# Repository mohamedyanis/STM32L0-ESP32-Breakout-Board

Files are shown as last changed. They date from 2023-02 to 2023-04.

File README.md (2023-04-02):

# STM32L0-ESP32 Breakout Board



This is a small breakout Printed Circuit Board (PCB) that is based on the STM32 microcontroller as well as the ESP32 dev module.
The PCB is designed using the free and open source software <a href="https://github.com/KiCad">KiCad</a>. 

## More Details
The PCB is based on the STM32L0 series, specifically the STM32L031G6U6 microcontroller which is a low power based MCU. The MCU is operated with a High Speed Internal (HSI) clock signal of a 16 MHz crystal oscillator (No external quartz is needed).<br><br>
It's operating with an input voltage from 12V to 5V. The input voltage will be filtered and reduced to 3V3 in order to power the STM32 MCU as well as the ESP32 module.<br><br>
The purpose of this PCB is to control the temperature with a PID controller. It has two connectors for that, one for reading temperature value with a thermostat, a thermocouple, or a temperature IC (LM36/LM35) that gives an analog signal, and the other connector is used to control the temperature using a Solid State Relay (SSR) controlled by a PWM signal.<br><br>
The data read from the STM32 MCU is transmitted to the ESP32 dev module via 'USART' protocol in order to send the data to the cloud and the temperature could be controlled wirelessly anywhere with a smart phone or a web application.<br><br>
STM32 MCU can be flashed using SWD programmer and the ESP32 dev module could be programmed using a USB-to-TTL converter.<br><br>

## Features :dart:
* [x] Four layers PCB
* [x] Low power
* [x] Small size
* [x] Very easy to use

## Thank _You_!
Please :star: this repo to help us improve the quality.
<br><br>

## PCB Block Diagram
PCB System Block
:---------------------:
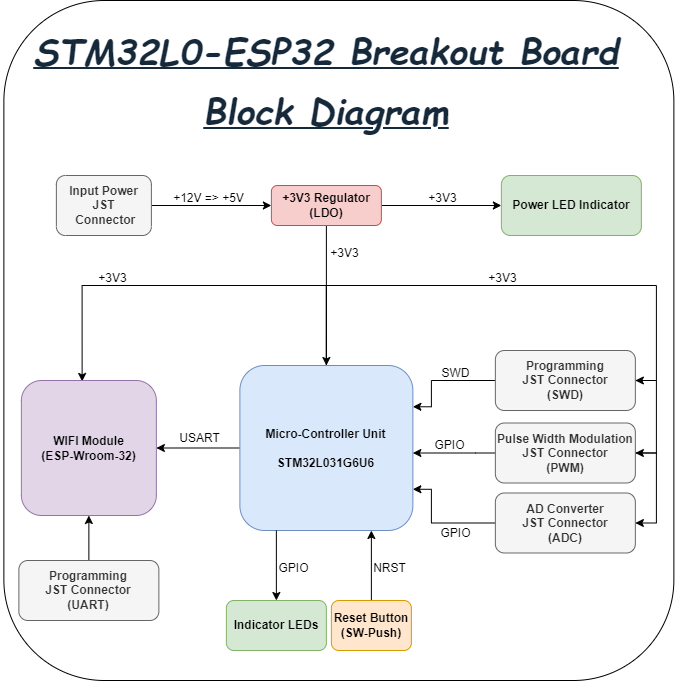
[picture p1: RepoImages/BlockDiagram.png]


## 3D Viewer
Front View           | Back View
:---------------------:|:------------------:
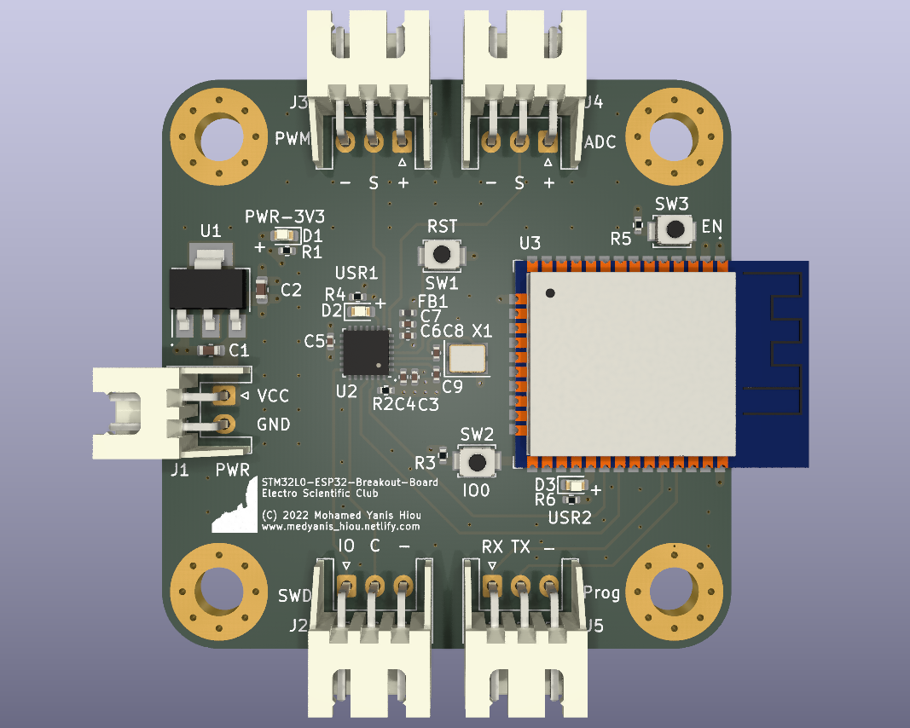
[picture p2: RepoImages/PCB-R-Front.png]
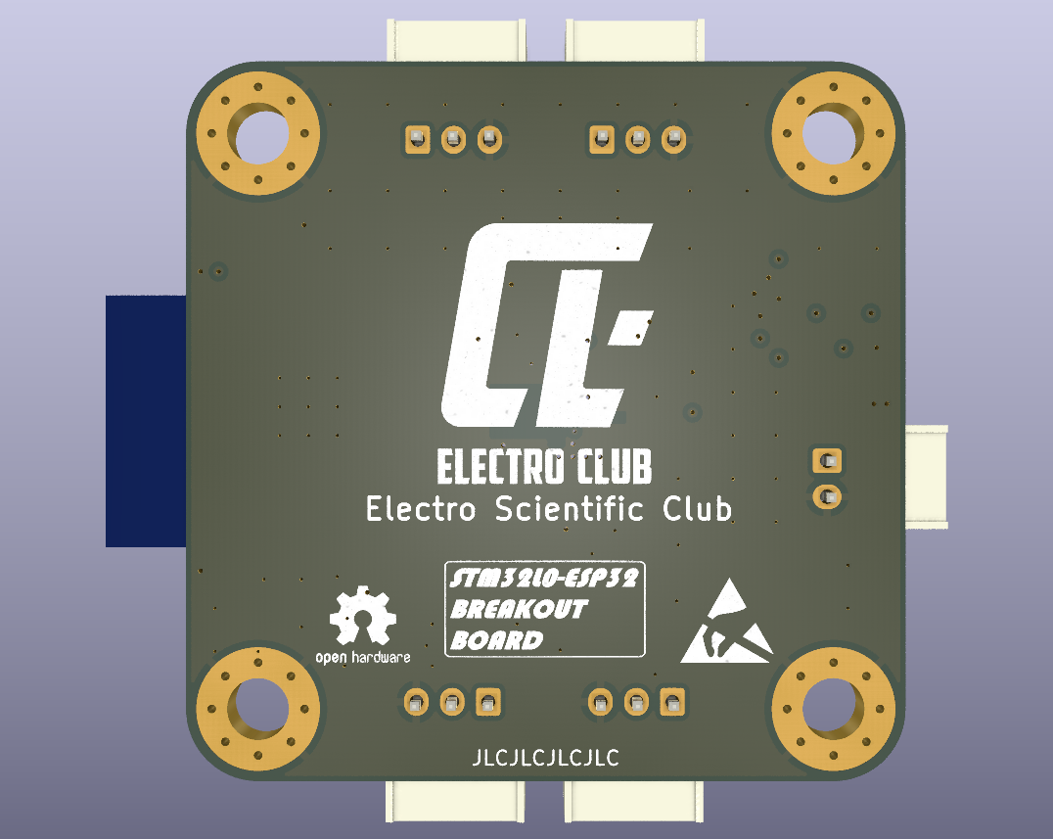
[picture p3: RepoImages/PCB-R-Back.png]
 | 
Side View 1         |  Side View 2
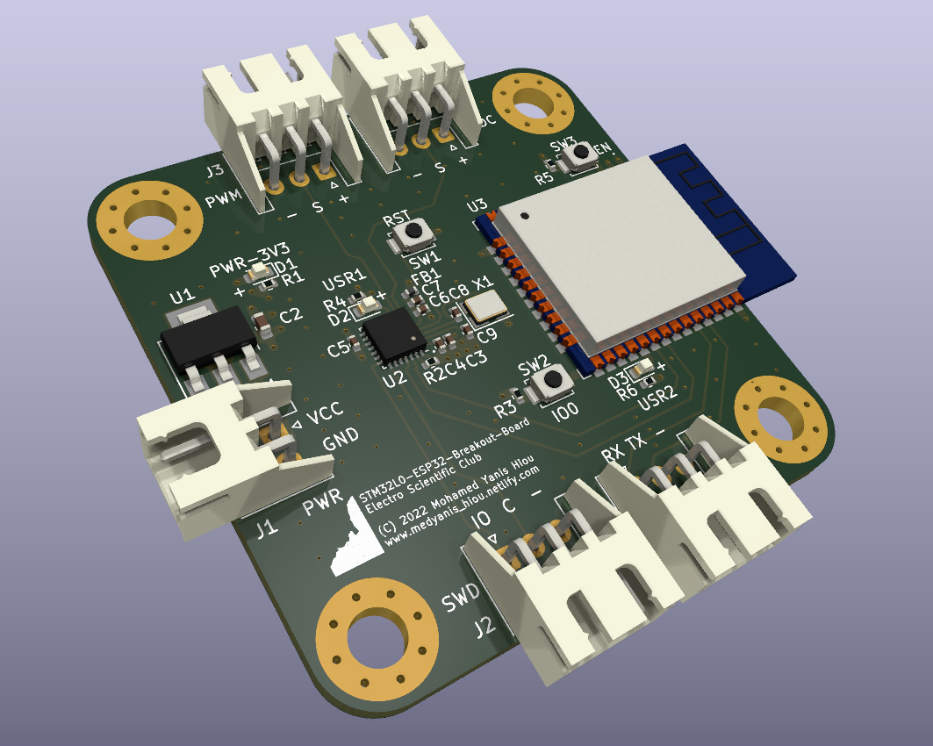
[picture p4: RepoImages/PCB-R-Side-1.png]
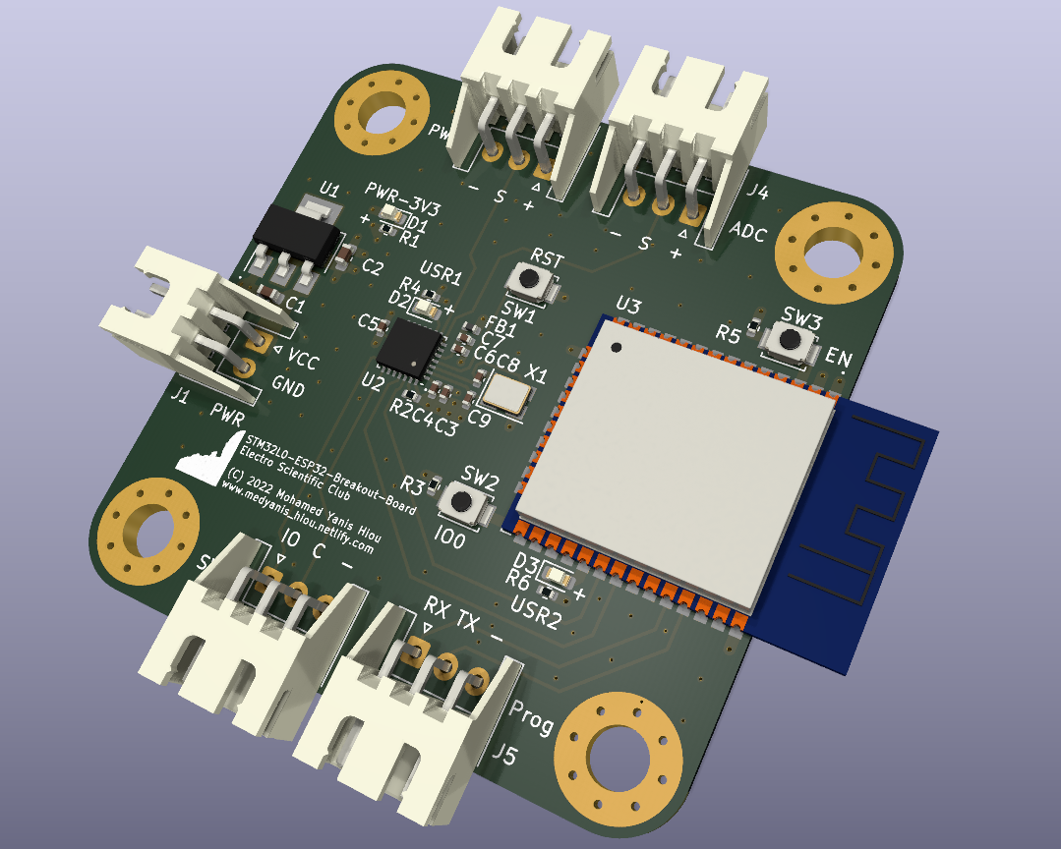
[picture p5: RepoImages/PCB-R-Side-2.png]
 | 
Side View 3         |  Side View 4
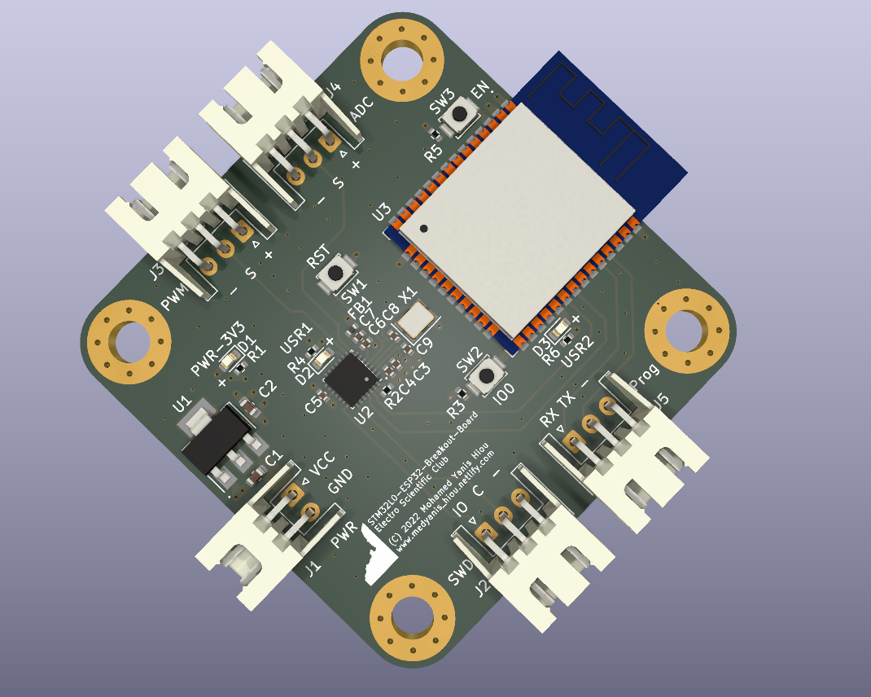
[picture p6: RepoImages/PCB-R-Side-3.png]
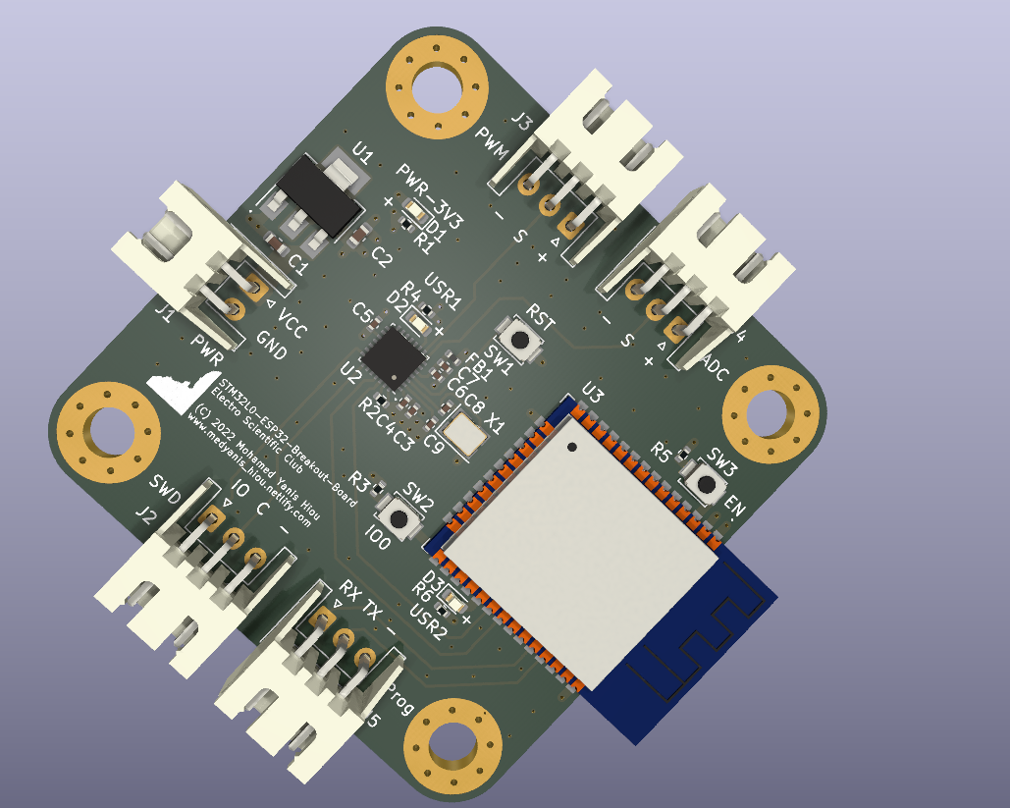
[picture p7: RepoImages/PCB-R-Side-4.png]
 | 

## Requirements

If you want to review the PCB or yoou wanna edit the schematics/layout, you only need to install KiCad software to your machine.

* Go to the <a href="https://www.kicad.org/download/">Official KiCad Download Page</a>.
* Select your operating system.
* Download the executable file and install it.

## Documentations
Open the [Datasheets](Datasheets) folder and you will find all the datasheets, applications notes, and design guidelines that help you understand the design better.

## How To Use It

1. Install this repository, click <a href="https://github.com/mohamedyanis/STM32L0-ESP32-Breakout-Board/archive/master.zip"> here </a> to install it. Or use git command:
```bach
git clone https://github.com/mohamedyanis/STM32L0-ESP32-Breakout-Board.git
```
2. Extract the folder and open it.
3. Navigate for the [Manufacturing](Manufacturing) folder.
4. Go to your best PCB manufacturer website and click on quote.
5. Upload the [STM32L0-ESP32-Breakout-Board-Gerber.rar](Manufacturing/Gerber/STM32L0-ESP32-Breakout-Board-Gerber.rar) in order to order the board.
6. In case you want to receive it assembled, upload the [STM32L0_ESP32_Breakout_Board_BOM.csv](Manufacturing/Assembly/STM32L0_ESP32_Breakout_Board_BOM.csv) and [STM32L0_ESP32_Breakout_Board_Components_Positions.csv](Manufacturing/Assembly/STM32L0_ESP32_Breakout_Board_Components_Positions.csv) files.

## License
The content of this project is licenced under the [BSD 3-Clause "New" or "Revised" License](LICENSE).

## Contributing 💡
If you want to contribute to this project and make it better with new ideas, your pull request is very welcomed.<br>
If you find any issue just put it in the repository issue section, thanks!<br><br>
.سبحَانَكَ اللَّهُمَّ وَبِحَمْدِكَ، أَشْهَدُ أَنْ لا إِلهَ إِلأَ انْتَ أَسْتَغْفِرُكَ وَأَتْوبُ إِلَيْكَ

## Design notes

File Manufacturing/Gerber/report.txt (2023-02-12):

Plotted to 'F:\Documents\Kicad\KiCad 6\STM32L0_ESP32_Breakout_Board\Manufacturing\Gerber\STM32L0_ESP32_Breakout_Board-F_Cu.gbr'.
Plotted to 'F:\Documents\Kicad\KiCad 6\STM32L0_ESP32_Breakout_Board\Manufacturing\Gerber\STM32L0_ESP32_Breakout_Board-In1_Cu.gbr'.
Plotted to 'F:\Documents\Kicad\KiCad 6\STM32L0_ESP32_Breakout_Board\Manufacturing\Gerber\STM32L0_ESP32_Breakout_Board-In2_Cu.gbr'.
Plotted to 'F:\Documents\Kicad\KiCad 6\STM32L0_ESP32_Breakout_Board\Manufacturing\Gerber\STM32L0_ESP32_Breakout_Board-B_Cu.gbr'.
Plotted to 'F:\Documents\Kicad\KiCad 6\STM32L0_ESP32_Breakout_Board\Manufacturing\Gerber\STM32L0_ESP32_Breakout_Board-F_Paste.gbr'.
Plotted to 'F:\Documents\Kicad\KiCad 6\STM32L0_ESP32_Breakout_Board\Manufacturing\Gerber\STM32L0_ESP32_Breakout_Board-B_Paste.gbr'.
Plotted to 'F:\Documents\Kicad\KiCad 6\STM32L0_ESP32_Breakout_Board\Manufacturing\Gerber\STM32L0_ESP32_Breakout_Board-F_Silkscreen.gbr'.
Plotted to 'F:\Documents\Kicad\KiCad 6\STM32L0_ESP32_Breakout_Board\Manufacturing\Gerber\STM32L0_ESP32_Breakout_Board-B_Silkscreen.gbr'.
Plotted to 'F:\Documents\Kicad\KiCad 6\STM32L0_ESP32_Breakout_Board\Manufacturing\Gerber\STM32L0_ESP32_Breakout_Board-F_Mask.gbr'.
Plotted to 'F:\Documents\Kicad\KiCad 6\STM32L0_ESP32_Breakout_Board\Manufacturing\Gerber\STM32L0_ESP32_Breakout_Board-B_Mask.gbr'.
Plotted to 'F:\Documents\Kicad\KiCad 6\STM32L0_ESP32_Breakout_Board\Manufacturing\Gerber\STM32L0_ESP32_Breakout_Board-Edge_Cuts.gbr'.
Created Gerber job file 'F:\Documents\Kicad\KiCad 6\STM32L0_ESP32_Breakout_Board\Manufacturing\Gerber\STM32L0_ESP32_Breakout_Board-job.gbrjob'.
Info: Done.

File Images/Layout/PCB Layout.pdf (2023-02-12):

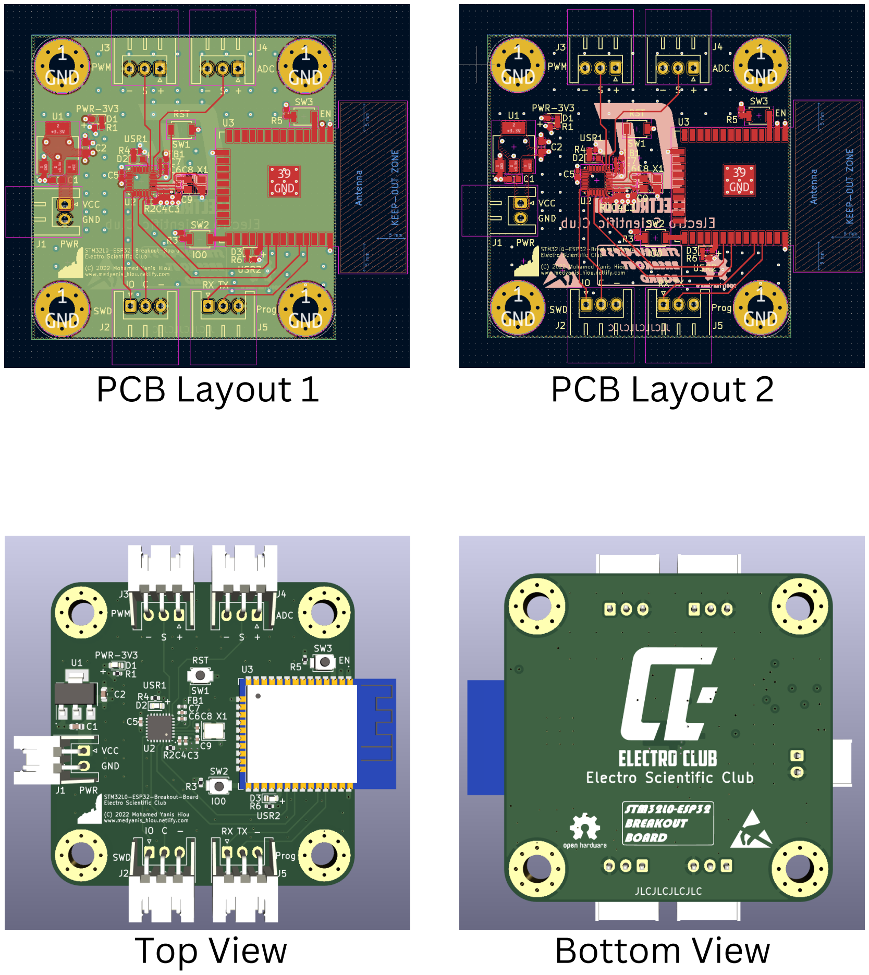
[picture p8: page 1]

PCB Layout 1 | PCB Layout 2
Top View | Bottom View

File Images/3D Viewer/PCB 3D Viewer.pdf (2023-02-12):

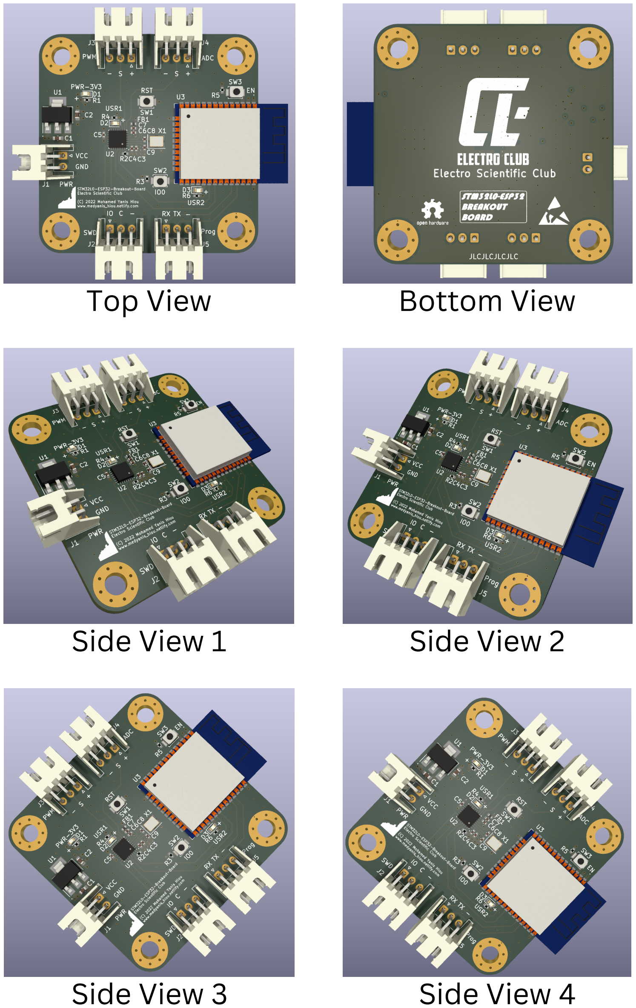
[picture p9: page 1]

Top View | Bottom View
Side View 1 | Side View 2
Side View 3 | Side View 4

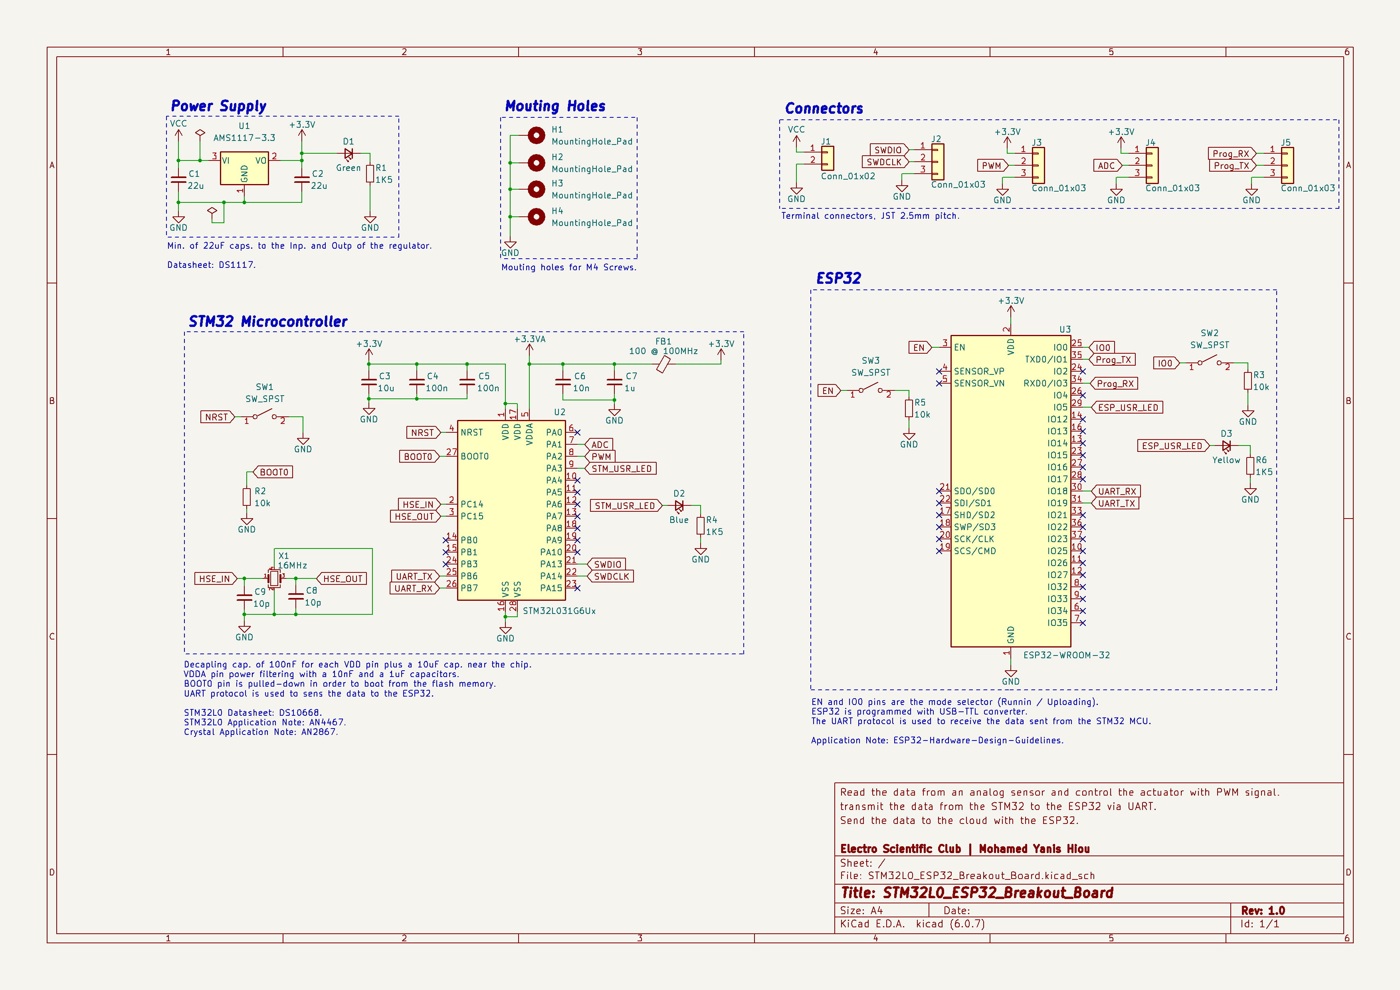
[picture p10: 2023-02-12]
Images/Schematics/STM32L0_ESP32_Breakout_Board_Schematics.png

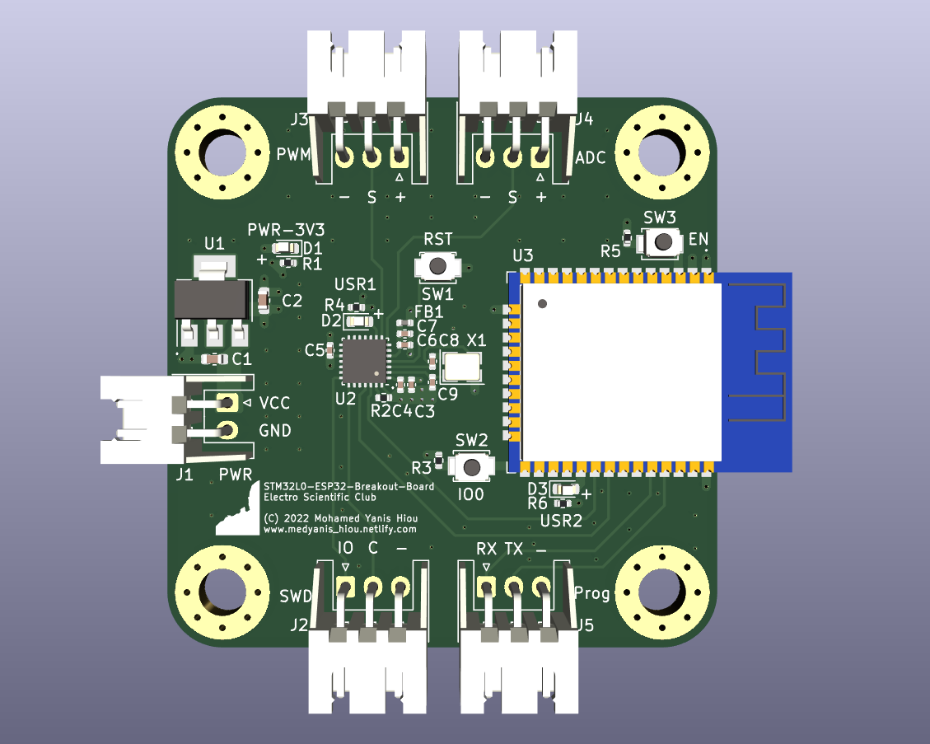
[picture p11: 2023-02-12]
Images/3D Viewer/PCB-NR-Front.png

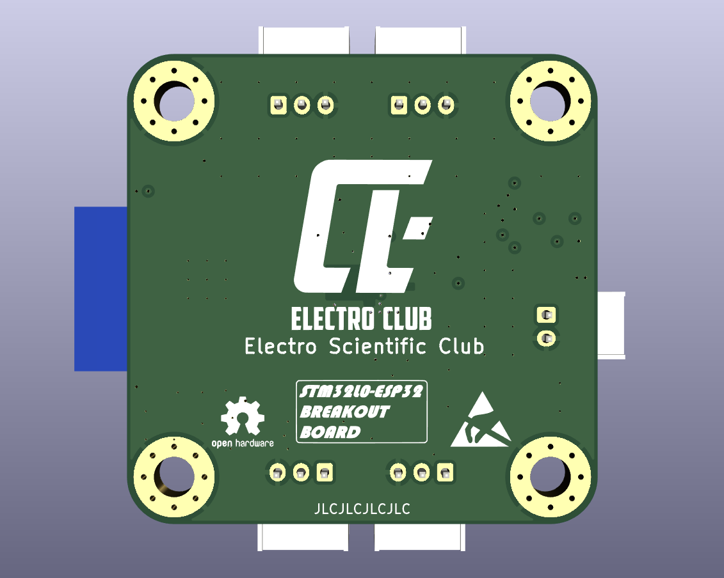
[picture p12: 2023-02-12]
Images/3D Viewer/PCB-NR-Back.png

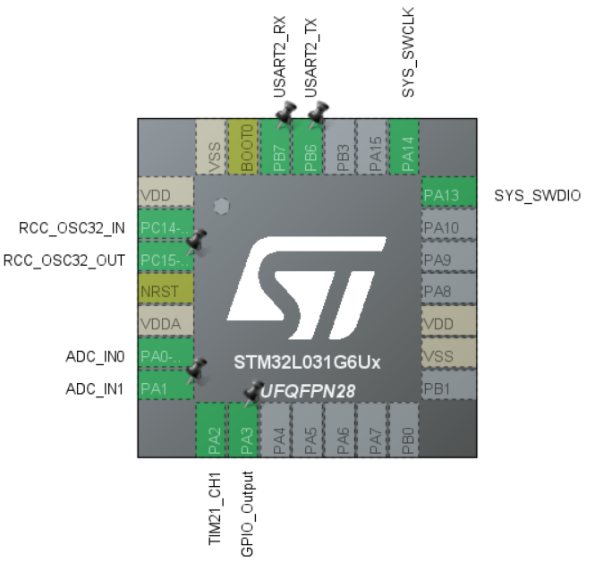
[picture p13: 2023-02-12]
Images/Pins Configuration/STM32L0-Pins-Configuration.png

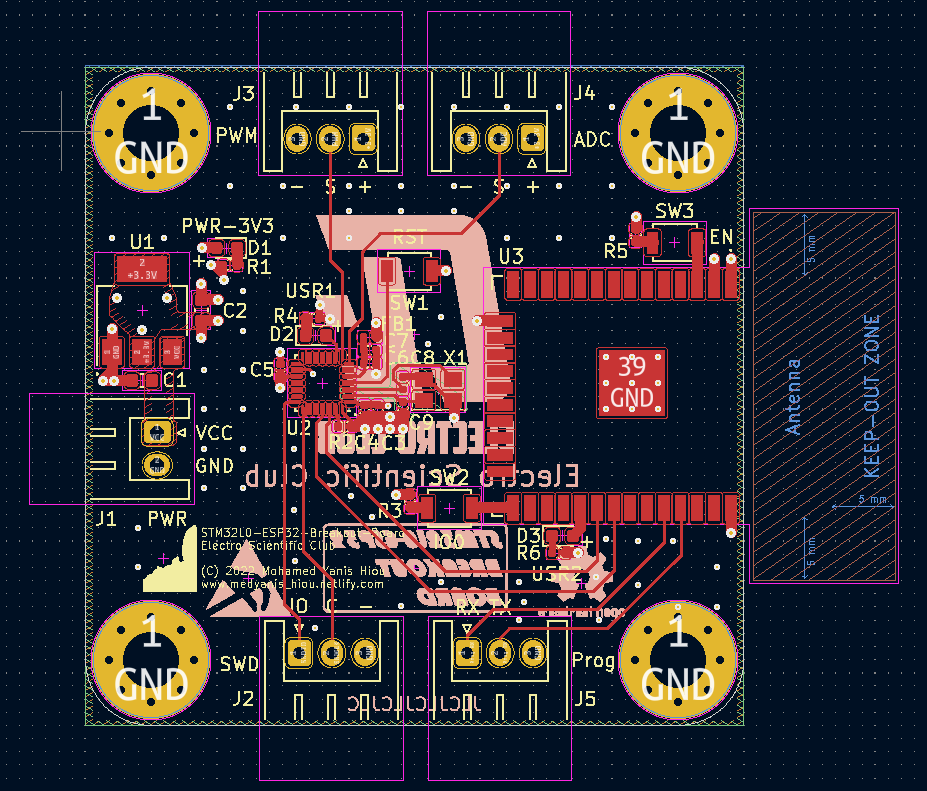
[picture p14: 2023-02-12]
Images/Layout/PCB-Layout-1.png

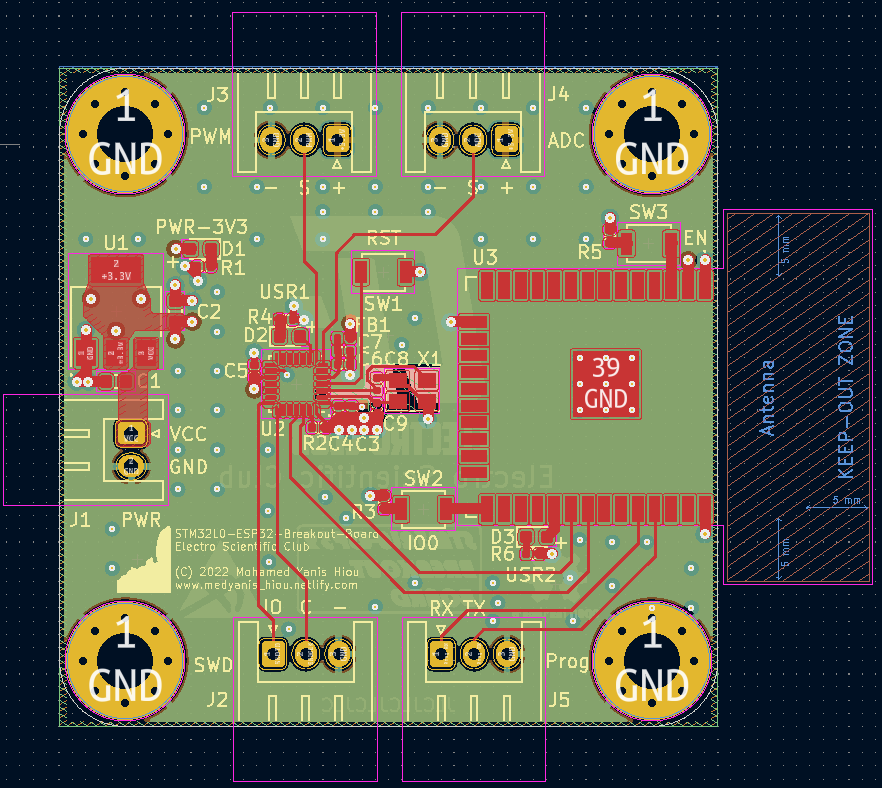
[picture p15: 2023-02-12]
Images/Layout/PCB-Layout-2.png

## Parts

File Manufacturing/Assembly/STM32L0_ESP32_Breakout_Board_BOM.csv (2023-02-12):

Designator | Quantity | Value | Footprint | LCSC Part # | Type
C1, C2, | 2 | 22u | C_0603_1608Metric | C59461 | SMD
C3, | 1 | 10u | C_0402_1005Metric | C15525 | SMD
C4, C5, | 2 | 100n | C_0402_1005Metric | C1525 | SMD
C6, | 1 | 10n | C_0402_1005Metric | C15195 | SMD
C7, | 1 | 1u | C_0402_1005Metric | C52923 | SMD
C8, C9, | 2 | 10p | C_0402_1005Metric | C32949 | DNP
D1, | 1 | Green | LED_0603_1608Metric | C72043 | SMD
D2, | 1 | Blue | LED_0603_1608Metric | C72041 | SMD
D3, | 1 | Yellow | LED_0603_1608Metric | C72038 | SMD
FB1, | 1 | 100 @ 100MHz | L_0402_1005Metric | C85817 | SMD
R1, R4, R6, | 3 | 1K5 | R_0402_1005Metric | C279987 | SMD
R2, R3, R5, | 3 | 10k | R_0402_1005Metric | C409612 | SMD
SW1, SW2, SW3, | 3 | SW_SPST | SW_SPST_B3U-1000P | C231329 | SMD
U1, | 1 | AMS1117-3.3 | SOT-223-3 | C6186 | SMD
U2, | 1 | STM32L031G6U6 | QFN-28_4x4mm | C96514 | SMD
U3, | 1 | ESP32-WROOM-32 | ESP32-WROOM-32 | C529582 | SMD
X1, | 1 | 16MHz | Crystal_SMD_TSX3225 | C13738 | DNP

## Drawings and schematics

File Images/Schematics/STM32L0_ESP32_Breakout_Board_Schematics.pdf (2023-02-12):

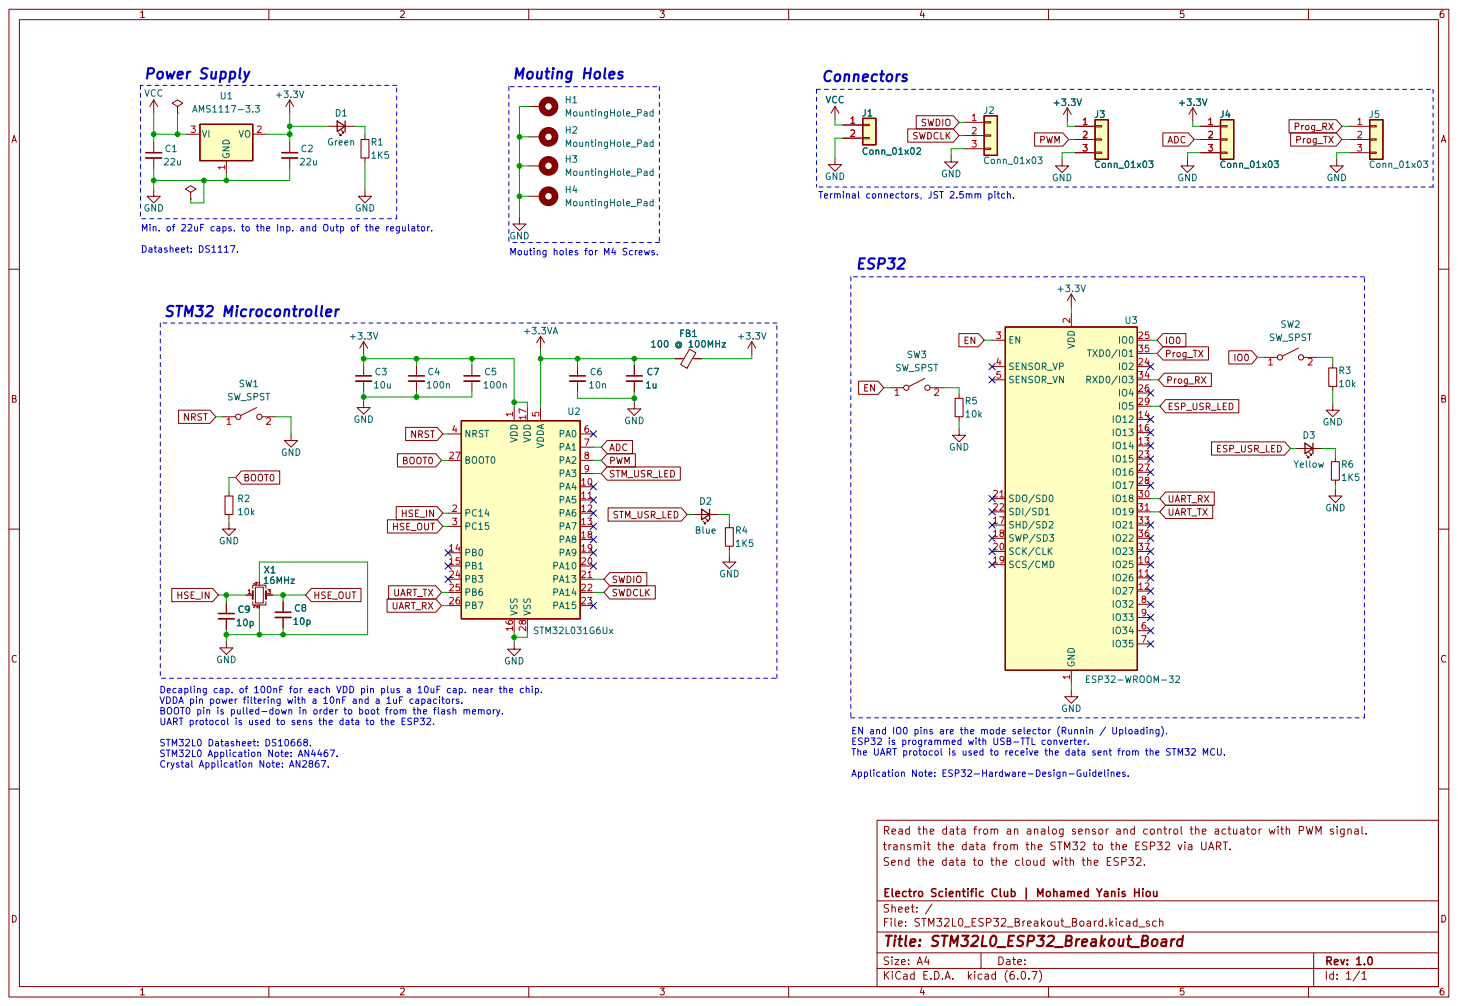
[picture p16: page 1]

Terminal connectors, JST 2.5mm pitch.
100 @ 100MHzGND

Min. of 22uF caps. to the Inp. and Outp of the regulator. Datasheet: DS1117. Decapling cap. of 100nF for each VDD pin plus a 10uF cap. near the chip.

2 SCK/CLK 20 SDO/SD0 21 SDI/SD1 22

1 PA4 10 PA5 11 PA6 12 PA7 13 PB0 14 PB1 15 VSS 16 VDD 17 PA8 18 PA9 19 PC14 2 PA10 20 PA13 21 PA14 22 PA15 23 PB3 24 PB6 25 PB7 26 BOOT0 27 VSS 28 PC15 3 NRST 4 VDDA

VDDA pin power filtering with a 10nF and a 1uF capacitors.
BOOT0 pin is pulled-down in order to boot from the flash memory.
UART protocol is used to sens the data to the ESP32. STM32L0 Datasheet: DS10668. STM32L0 Application Note: AN4467.

EN and IO0 pins are the mode selector (Runnin / Uploading).
ESP32 is programmed with USB-TTL converter.
The UART protocol is used to receive the data sent from the STM32 MCU.

Application Note: ESP32-Hardware-Design-Guidelines.

transmit the data from the STM32 to the ESP32 via UART. Read the data from an analog sensor and control the actuator with PWM signal.

File: STM32L0_ESP32_Breakout_Board.kicad_sch Sheet: / Electro Scientific Club | Mohamed Yanis Hiou Send the data to the cloud with the ESP32.

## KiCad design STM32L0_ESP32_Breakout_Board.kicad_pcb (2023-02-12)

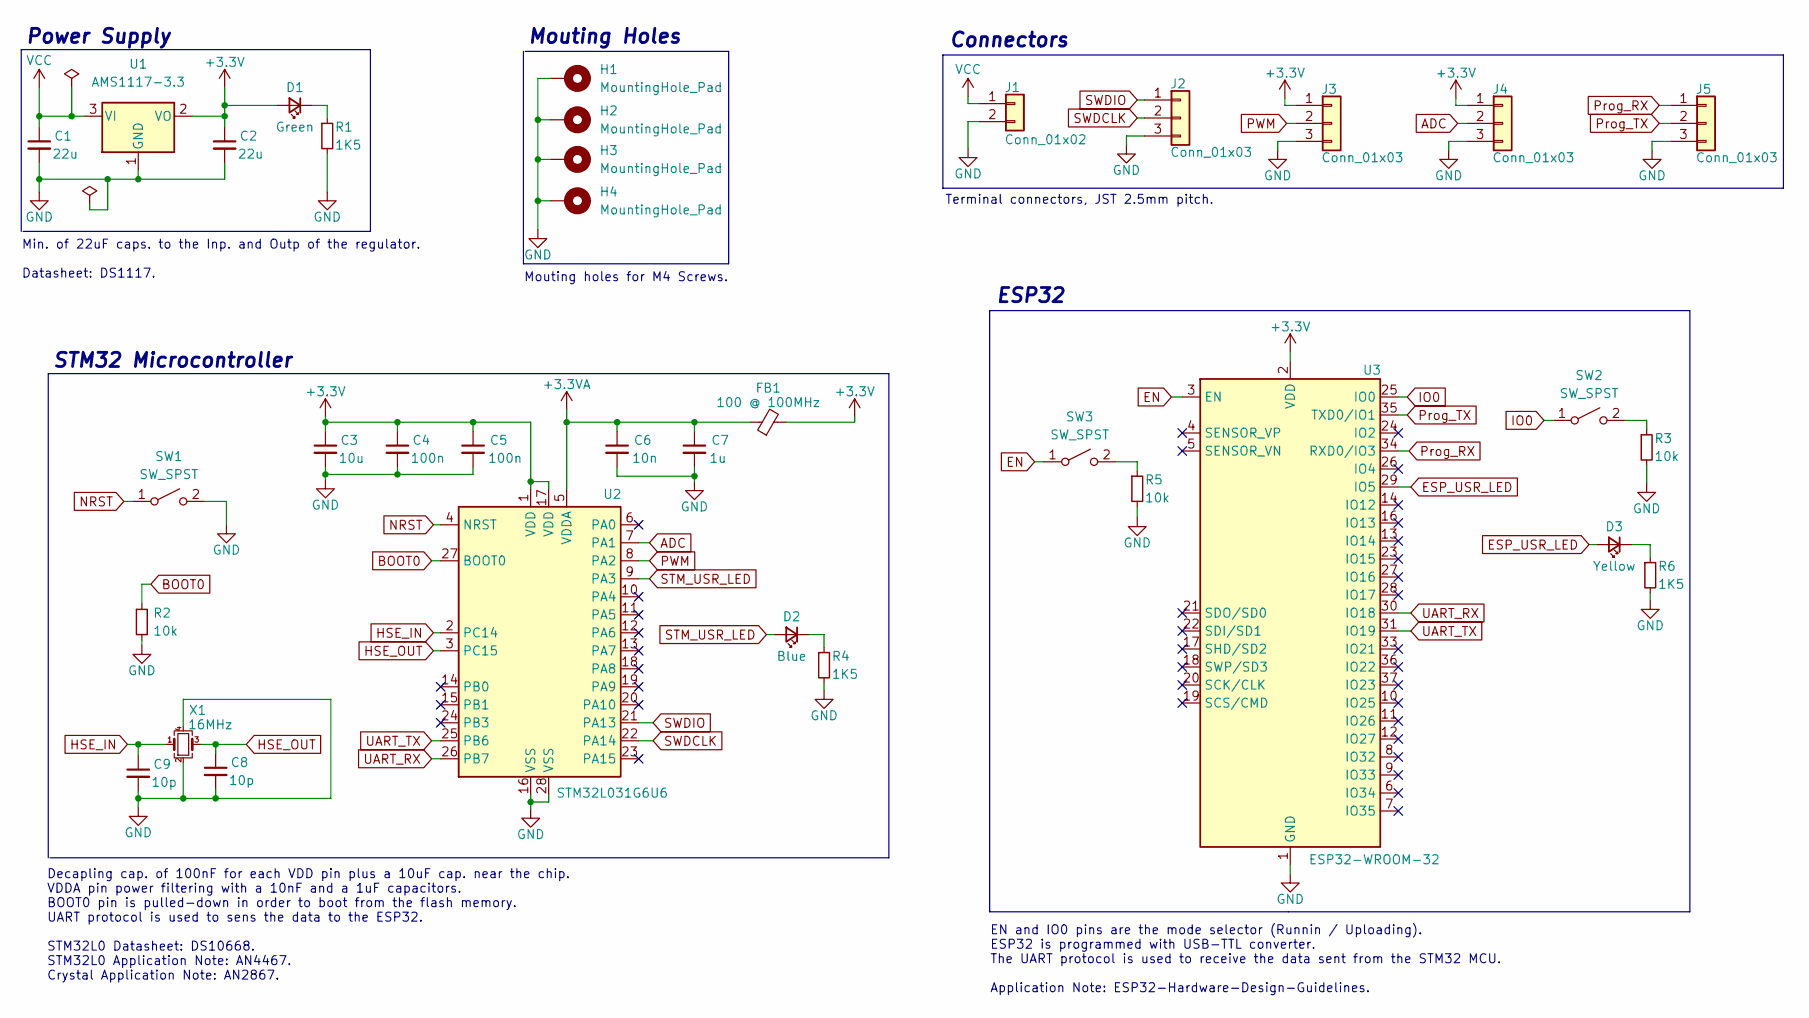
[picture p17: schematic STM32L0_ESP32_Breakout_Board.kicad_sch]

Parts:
C1, C2: 22u; C_0603_1608Metric
C3: 10u; C_0402_1005Metric
C4, C5: 100n; C_0402_1005Metric
C6: 10n; C_0402_1005Metric
C7: 1u; C_0402_1005Metric
C8, C9: 10p; C_0402_1005Metric
D1: Green; LED_0603_1608Metric
D2: Blue; LED_0603_1608Metric
D3: Yellow; LED_0603_1608Metric
FB1: 100 @ 100MHz; L_0402_1005Metric
H1, H2, H3, H4: MountingHole_Pad; MountingHole_4.3mm_M4_Pad_Via
J1: Conn_01x02; JST_XH_S2B-XH-A_1x02_P2.50mm_Horizontal
J2, J3, J4, J5: Conn_01x03; JST_XH_S3B-XH-A_1x03_P2.50mm_Horizontal
R1, R4, R6: 1K5; R_0402_1005Metric
R2, R3, R5: 10k; R_0402_1005Metric
SW1, SW2, SW3: SW_SPST; SW_SPST_B3U-1000P
U1: AMS1117-3.3; SOT-223-3_TabPin2
U2: STM32L031G6U6; QFN-28_4x4mm_P0.5mm
U3: ESP32-WROOM-32
X1: 16MHz; Crystal_SMD_SeikoEpson_TSX3225-4Pin_3.2x2.5mm

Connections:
+3.3V: C2.1, C3.1, C4.1, C5.1, D1.2 (A), FB1.2, J3.1, J4.1, U1.2 (VO), U2.1 (VDD), U2.17 (VDD), U3.2 (VDD)
+3.3VA: C6.1, C7.1, FB1.1, U2.5 (VDDA)
ADC: J4.2, U2.7 (PA1)
BOOT0: R2.1, U2.27 (BOOT0)
EN: SW3.1 (A), U3.3 (EN)
ESP_USR_LED: D3.2 (A), U3.29 (IO5)
GND: C1.2, C2.2, C3.2, C4.2, C5.2, C6.2, C7.2, C8.2, C9.2, H1.1, H2.1, H3.1, H4.1, J1.2, J2.3, J3.3, J4.3, J5.3, R1.2, R2.2, R3.2, R4.2, R5.2, R6.2, SW1.2 (B), U1.1 (GND), U2.16 (VSS), U2.28 (VSS), U3.1 (GND), U3.15 (GND), U3.38 (GND), U3.39 (GND), X1.2, X1.4
HSE_IN: C9.1, U2.2 (PC14), X1.1
HSE_OUT: C8.1, U2.3 (PC15), X1.3
IO0: SW2.1 (A), U3.25 (IO0)
NRST: SW1.1 (A), U2.4 (NRST)
unnamed: D1.1 (K), R1.1
unnamed: D2.1 (K), R4.1
unnamed: D3.1 (K), R6.1
unnamed: R3.1, SW2.2 (B)
unnamed: R5.1, SW3.2 (B)
PWM: J3.2, U2.8 (PA2)
Prog_RX: J5.1, U3.34 (RXD0/IO3)
Prog_TX: J5.2, U3.35 (TXD0/IO1)
STM_USR_LED: D2.2 (A), U2.9 (PA3)
SWDCLK: J2.2, U2.22 (PA14)
SWDIO: J2.1, U2.21 (PA13)
UART_RX: U2.26 (PB7), U3.30 (IO18)
UART_TX: U2.25 (PB6), U3.31 (IO19)
VCC: C1.1, J1.1, U1.3 (VI)

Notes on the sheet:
Min. of 22uF caps. to the Inp. and Outp of the regulator. Datasheet: DS1117.
Terminal connectors, JST 2.5mm pitch.
Power Supply
Mouting Holes
Connectors
STM32 Microcontroller
Decapling cap. of 100nF for each VDD pin plus a 10uF cap. near the chip. VDDA pin power filtering with a 10nF and a 1uF capacitors. BOOT0 pin is pulled-down in order to boot from the flash memory. UART protocol is used to sens the data to the ESP32. STM32L0 Datasheet: DS10668. STM32L0 Application N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
EN and IO0 pins are the mode selector (Runnin / Uploading). ESP32 is programmed with USB-TTL converter. The UART protocol is used to receive the data sent from the STM32 MCU. Application Note: ESP32-Hardware-Design-Guidelines.
ESP32
Mouting holes for M4 Screws.

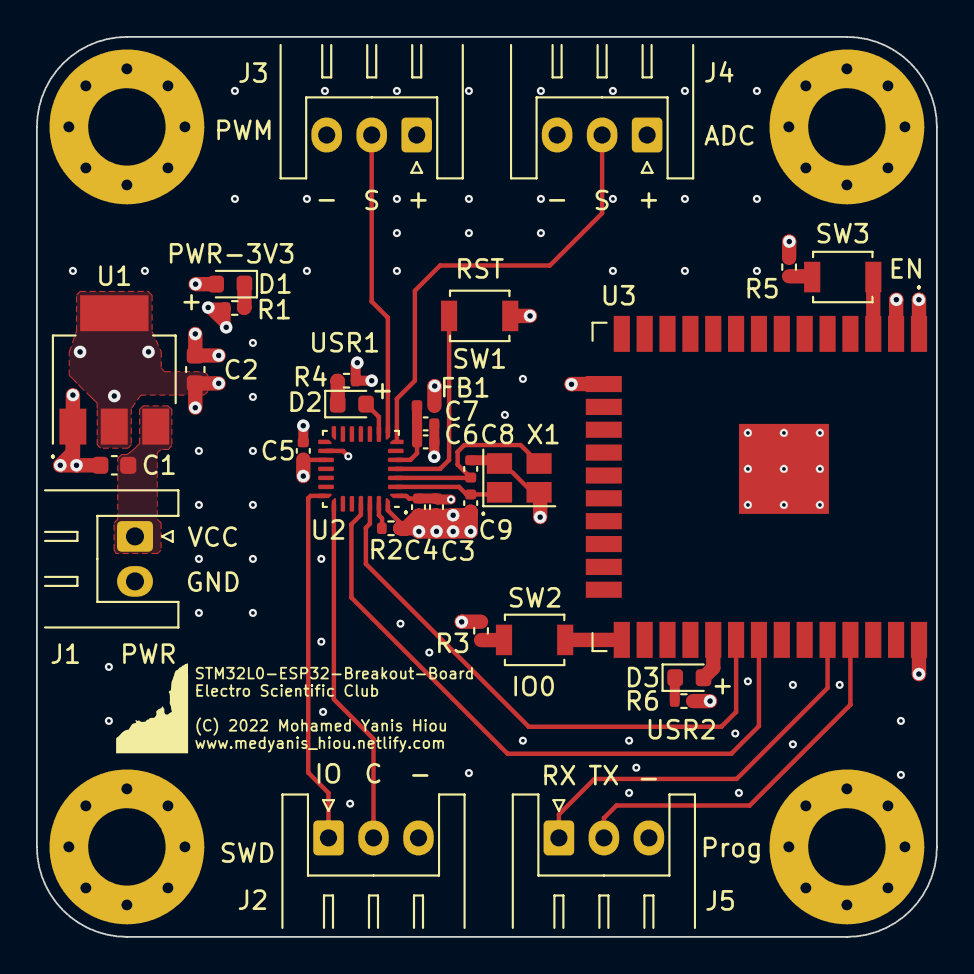
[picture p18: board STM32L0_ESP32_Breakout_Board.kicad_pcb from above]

Board: 4 copper layers, 50.0 x 50.0 mm, 35 parts (0 on the bottom side), 25 nets.

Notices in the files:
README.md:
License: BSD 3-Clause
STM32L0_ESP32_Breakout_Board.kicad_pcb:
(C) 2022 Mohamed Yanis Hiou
